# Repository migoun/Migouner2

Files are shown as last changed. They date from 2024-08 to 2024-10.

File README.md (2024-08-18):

# Migouner2
Second Mechanical Keyboard. This is a follow up of a keyboard, built 6 years ago: https://github.com/migoun/mechanical_keyboard_mac

Changes:
- STM32 MCU instead of Atmel Chip
- Addressable RGB LEDs backlight for each key (therefore the STM32)
- USB Micro port, to make this as low profile as possible
- Using JLCs Assembly service for one side of the board. 6 years ago, that didn't exist - or at least not for free. So i soldered everything back then
- First tries with printed 3D casings. Eventually CNC machining at a later stage

This time i start with a dev board, instead the whole keyboard:

**Front**
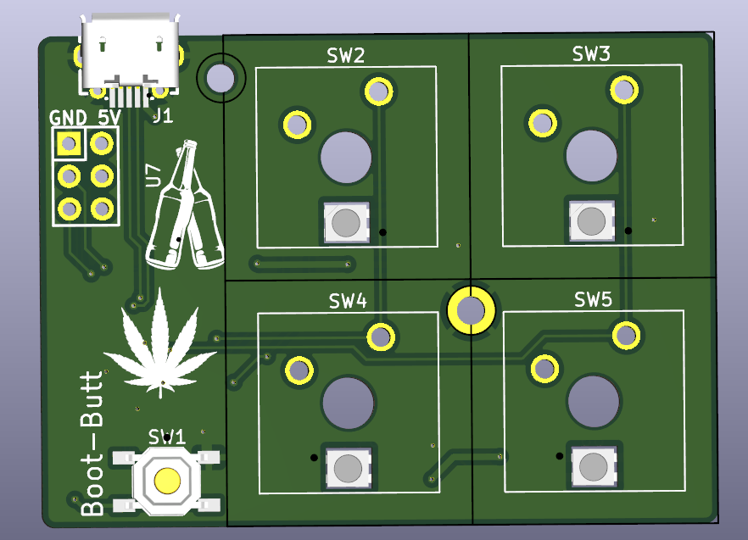
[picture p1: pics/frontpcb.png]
front


**Back**
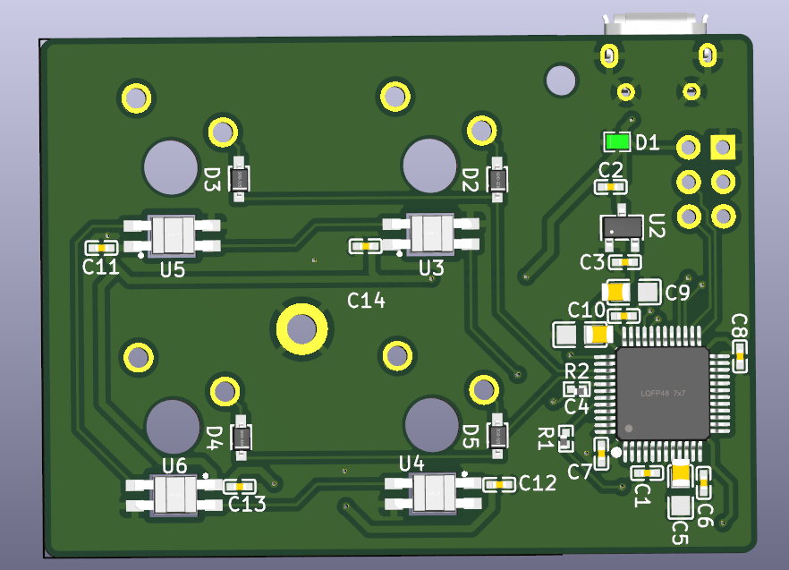
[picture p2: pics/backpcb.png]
back


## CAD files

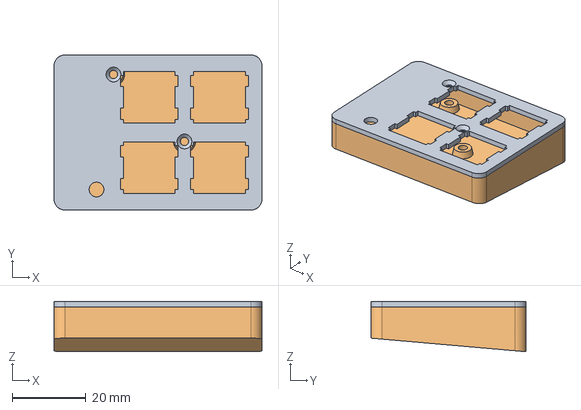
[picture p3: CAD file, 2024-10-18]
3DObjects/Migouner2Case.step
56.4 x 42.1 x 13.7 mm
MountingPlateBody
CaseBody

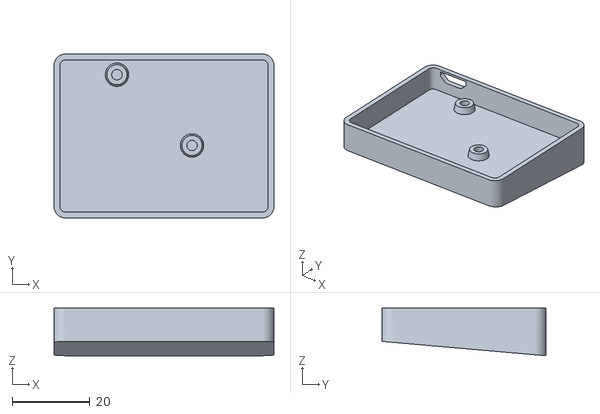
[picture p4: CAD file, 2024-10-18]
3DObjects/Migouner2-Migouner2CaseBody.stl
56.4 x 42.1 x 12.2

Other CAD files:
3DObjects/Migouner2Case.3mf

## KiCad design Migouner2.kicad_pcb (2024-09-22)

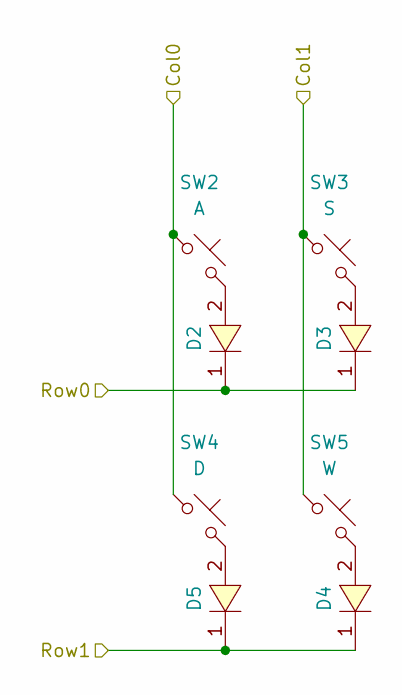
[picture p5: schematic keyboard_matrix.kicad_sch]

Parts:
D2: A; SOD-323_L1.8-W1.3-LS2.5-RD; LCSC Part C2128
D3: S; SOD-323_L1.8-W1.3-LS2.5-RD; LCSC Part C2128
D4: W; SOD-323_L1.8-W1.3-LS2.5-RD; LCSC Part C2128
D5: D; SOD-323_L1.8-W1.3-LS2.5-RD; LCSC Part C2128
SW2: A; SW_Cherry_MX_1.00u_Plate
SW3: S; SW_Cherry_MX_1.00u_Plate
SW4: D; SW_Cherry_MX_1.00u_Plate
SW5: W; SW_Cherry_MX_1.00u_Plate

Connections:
/Keyboard Matrix/Col0: SW2.1, SW4.1; also elsewhere on the board
/Keyboard Matrix/Col1: SW3.1, SW5.1; also elsewhere on the board
/Keyboard Matrix/Row0: D2.1, D3.1; also elsewhere on the board
/Keyboard Matrix/Row1: D4.1, D5.1; also elsewhere on the board
unnamed: D2.2, SW2.2
unnamed: D3.2, SW3.2
unnamed: D4.2, SW5.2
unnamed: D5.2, SW4.2

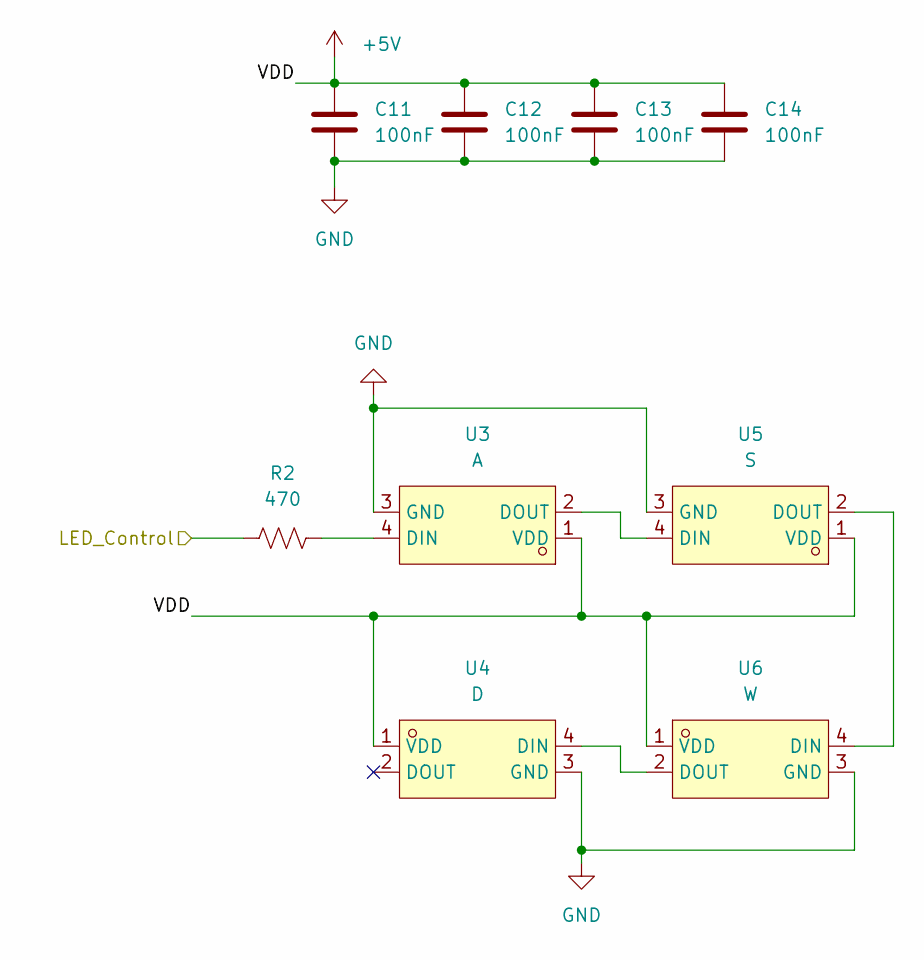
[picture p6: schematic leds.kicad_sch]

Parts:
C11, C12, C13, C14: 100nF; C0402; LCSC Part C5448875
R2: 470; R0402; LCSC Part C25117
U3: A; LED-SMD_L3.2-W2.8-TR; LCSC Part C5149201
U4: D; LED-SMD_L3.2-W2.8-TR; LCSC Part C5149201
U5: S; LED-SMD_L3.2-W2.8-TR; LCSC Part C5149201
U6: W; LED-SMD_L3.2-W2.8-TR; LCSC Part C5149201

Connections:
+5V: C11.1, C12.1, C13.1, C14.1, U3.1 (VDD), U4.1 (VDD), U5.1 (VDD), U6.1 (VDD); also elsewhere on the board
/RGB LEDs/LED_Control: R2.1; also elsewhere on the board
GND: C11.2, C12.2, C13.2, C14.2, U3.3 (GND), U4.3 (GND), U5.3 (GND), U6.3 (GND); also elsewhere on the board
unnamed: R2.2, U3.4 (DIN)
unnamed: U3.2 (DOUT), U5.4 (DIN)
unnamed: U4.4 (DIN), U6.2 (DOUT)
unnamed: U5.2 (DOUT), U6.4 (DIN)

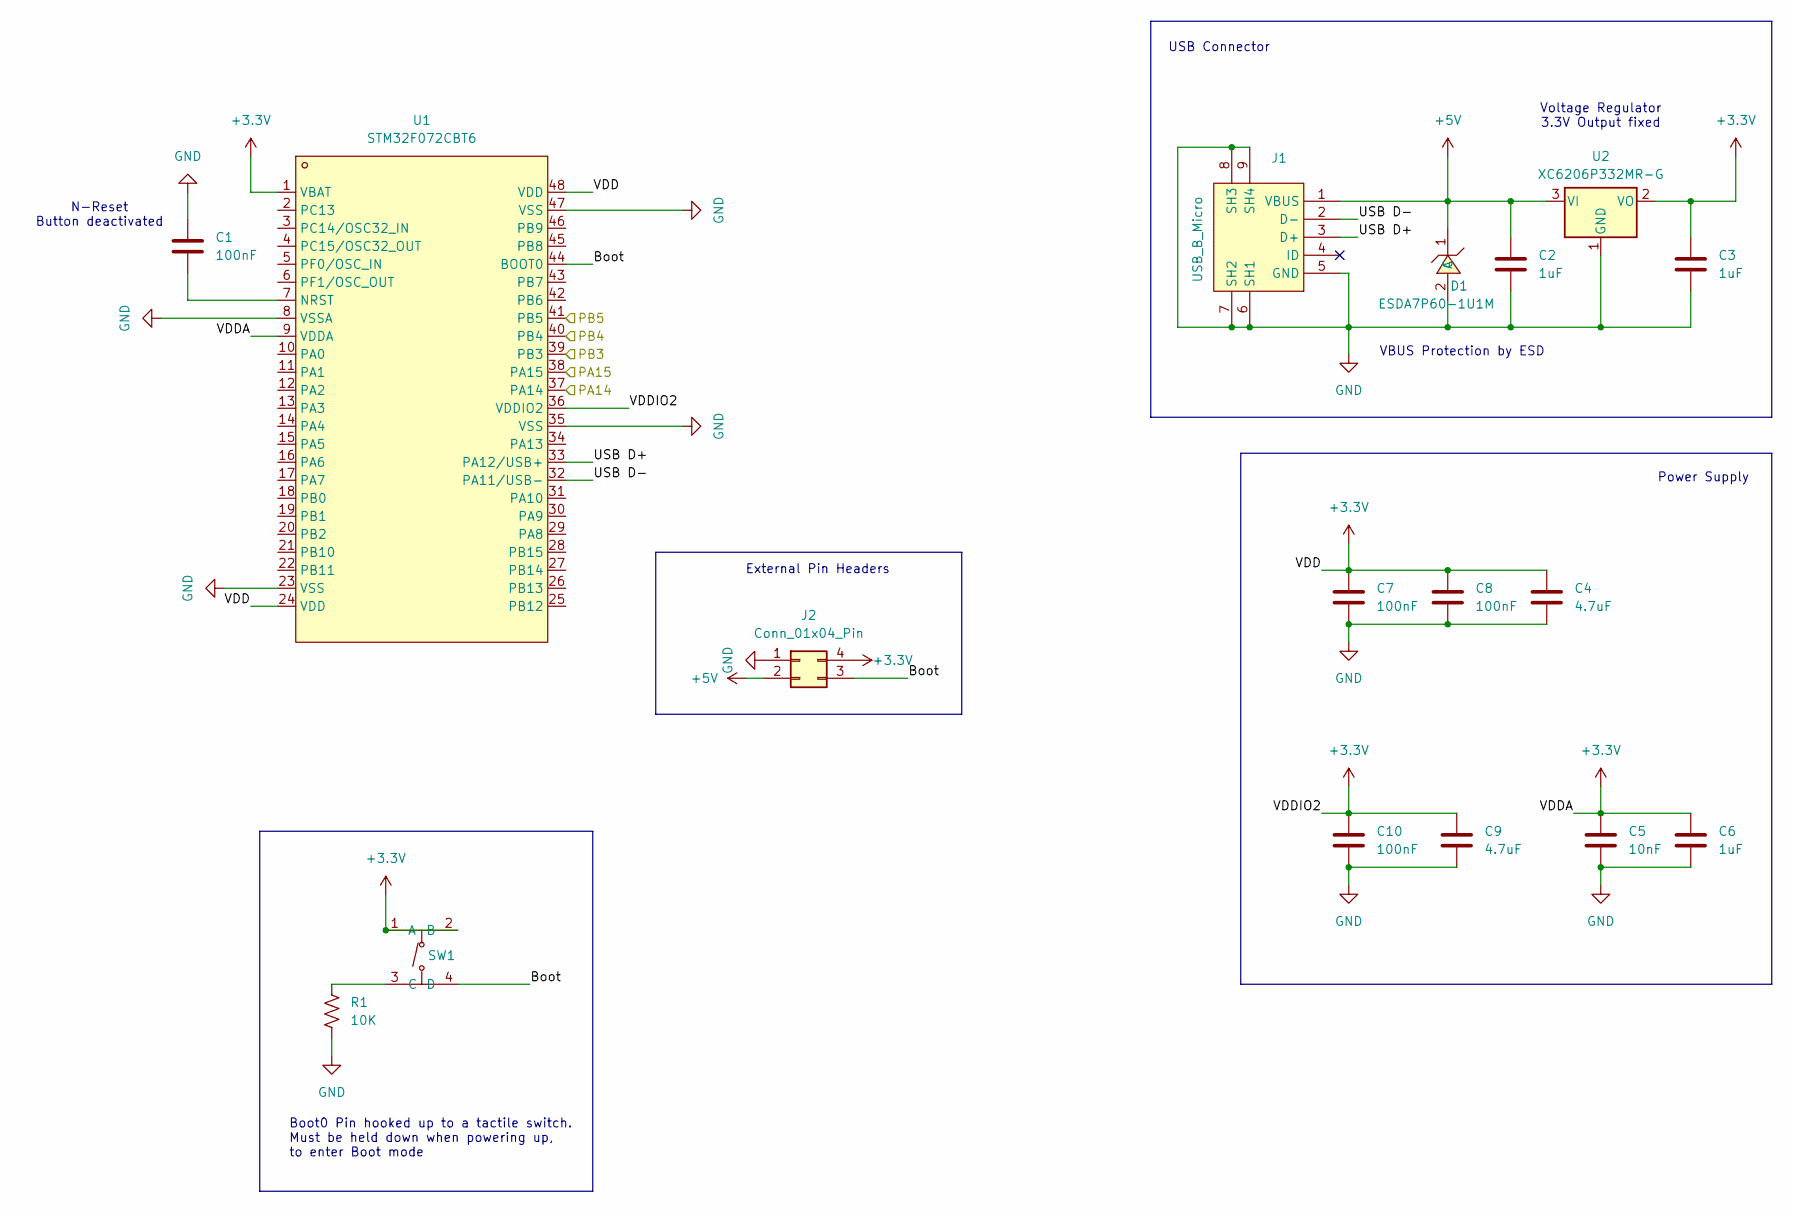
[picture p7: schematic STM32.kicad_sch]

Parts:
C1, C7, C8, C10: 100nF; C0402; LCSC Part C5448875
C2, C3, C6: 1uF; C0402; LCSC Part C14445
C4, C9: 4.7uF; C0805; LCSC Part C469525
C5: 10nF; C0805; LCSC Part C7393933
D1: ESDA7P60-1U1M; D1610-RD; LCSC Part C1975146
J1: USB_B_Micro; MICRO-USB-SMD_MICROXNJ; LCSC Part C404969
J2: Conn_01x04_Pin; PinHeader_2x02_P1.27mm_Vertical
R1: 10K; R0402; LCSC Part C191915
SW1: SW-SMD_4P-L5.1-W5.1-P3.70-LS6.5-TL-2; LCSC Part C318884
U1: STM32F072CBT6; LQFP-48_L7.0-W7.0-P0.50-LS9.0-BL; LCSC Part C81720
U2: XC6206P332MR-G; SOT-23-3_L2.9-W1.6-P1.90-LS2.8-BR; LCSC Part C5446

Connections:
+3.3V: C3.1, C4.1, C5.1, C6.1, C7.1, C8.1, C9.1, C10.1, J2.4, SW1.1 (A), SW1.2 (B), U1.1 (VBAT), U1.9 (VDDA), U1.24 (VDD), U1.36 (VDDIO2), U1.48 (VDD), U2.2 (VO)
+5V: C2.1, D1.1 (C), J1.1 (VBUS), J2.2, U2.3 (VI); also elsewhere on the board
/Keyboard Matrix/Col0: U1.37 (PA14); also elsewhere on the board
/Keyboard Matrix/Col1: U1.38 (PA15); also elsewhere on the board
/Keyboard Matrix/Row0: U1.39 (PB3); also elsewhere on the board
/Keyboard Matrix/Row1: U1.40 (PB4); also elsewhere on the board
/RGB LEDs/LED_Control: U1.41 (PB5); also elsewhere on the board
/STM32/Boot: J2.3, SW1.4 (D), U1.44 (BOOT0)
/STM32/USB D+: J1.3 (D+), U1.33 (PA12/USB+)
/STM32/USB D-: J1.2 (D-), U1.32 (PA11/USB-)
GND: C1.1, C2.2, C3.2, C4.2, C5.2, C6.2, C7.2, C8.2, C9.2, C10.2, D1.2 (A), J1.5 (GND), J1.6 (SH1), J1.7 (SH2), J1.8 (SH3), J1.9 (SH4), J2.1, R1.2, U1.8 (VSSA), U1.23 (VSS), U1.35 (VSS), U1.47 (VSS), U2.1 (GND); also elsewhere on the board
unnamed: R1.1, SW1.3 (C)
unnamed: C1.2, U1.7 (NRST)

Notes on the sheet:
Boot0 Pin hooked up to a tactile switch. Must be held down when powering up, to enter Boot mode
N-Reset Button deactivated
USB Connector
Power Supply
VBUS Protection by ESD
External Pin Headers
Voltage Regulator 3.3V Output fixed

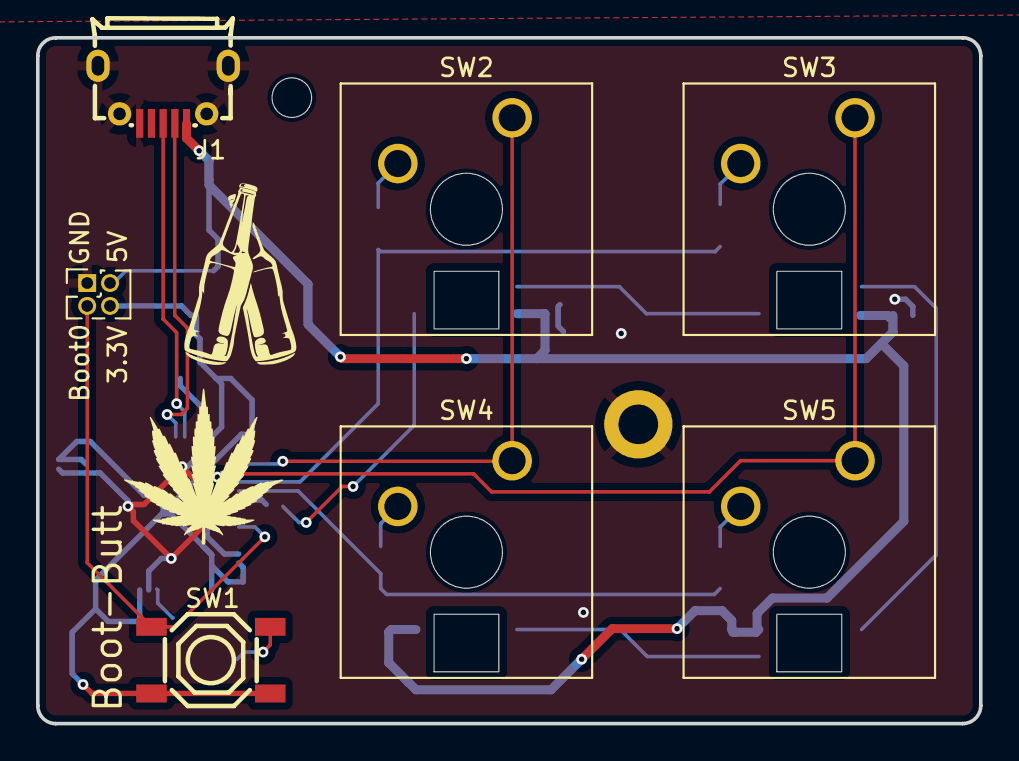
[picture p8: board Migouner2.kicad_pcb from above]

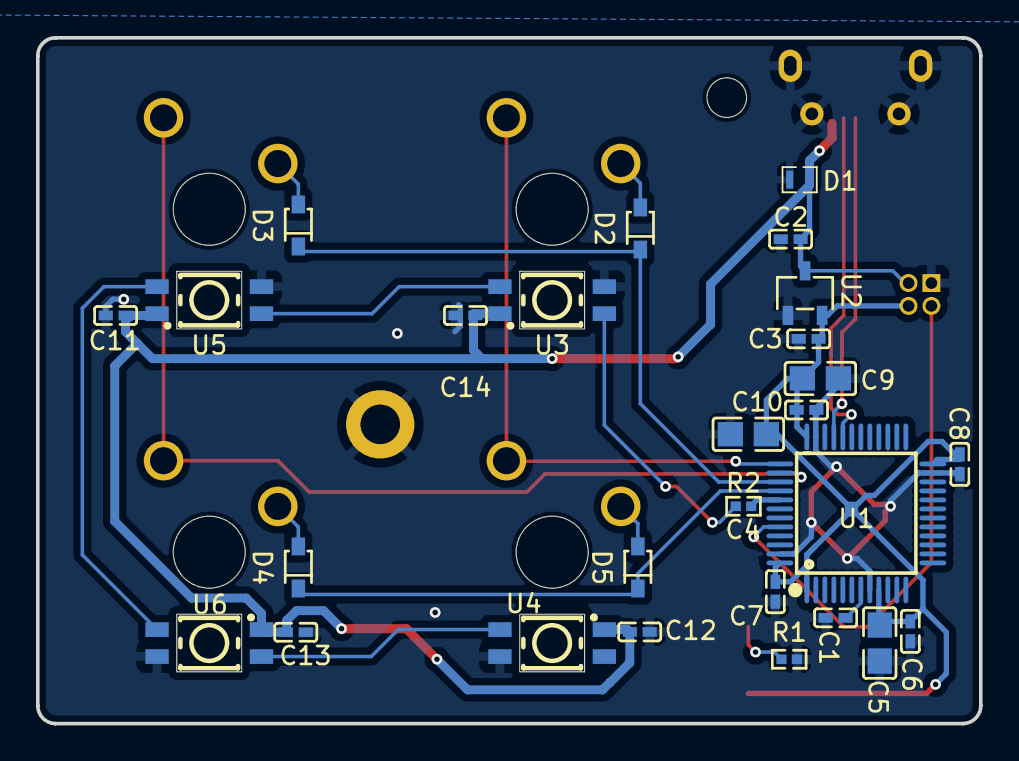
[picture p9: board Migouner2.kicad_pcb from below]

Board: 2 copper layers, 52.4 x 38.1 mm, 34 parts (27 on the bottom side), 21 nets.

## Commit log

2024-08-18 Initial Commit. STM32 Devboard with 4 switches and RGB Leds
    [Migouner2.kicad_pcb, Migouner2.kicad_sch, STM32.kicad_sch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]
2024-09-22 Corrected Devboard
    [Migouner2.kicad_pcb, STM32.kicad_sch]
